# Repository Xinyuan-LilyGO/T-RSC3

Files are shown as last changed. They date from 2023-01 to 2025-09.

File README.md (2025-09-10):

<h1 align = "center">🌟LILYGO T-RSC3 & RSS3 🌟</h1>

<h3 align = "left">Quick start:</h3>

**USE Arduino IDE**

1. Install the current upstream Arduino IDE at the 1.8 level or later. The current version is at the [Arduino website](http://www.arduino.cc/en/main/software).
2. Start Arduino and open Preferences window. In additional board manager add url: https://raw.githubusercontent.com/espressif/arduino-esp32/gh-pages/package_esp32_index.json .separating them with commas.
3. Copy all folders in [lib folder](./lib/)  to Arduino library folder (e.g. C:\Users\YourName\Documents\Arduino\libraries)
4. Open ArduinoIDE  ,`Tools` , Look at the picture to choose
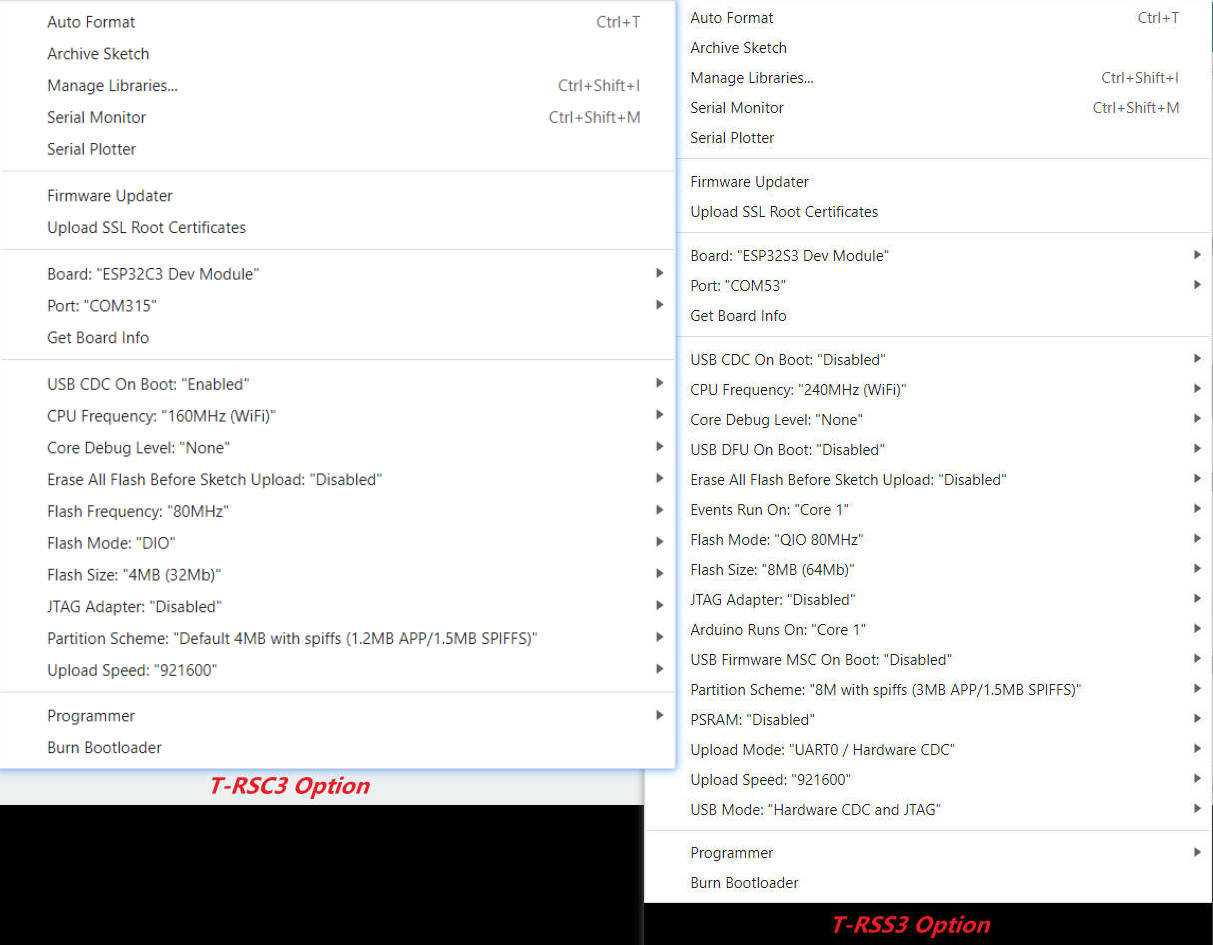
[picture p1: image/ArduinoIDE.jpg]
setting
   

**USE PlatformIO**

1. Install [Visual Studio Code](https://code.visualstudio.com/) and [Python](https://www.python.org/)
2. Search for the `PlatformIO` plugin in the `VisualStudioCode` extension and install it.
3. After the installation is complete, you need to restart `VisualStudioCode`
4. After restarting `VisualStudioCode`, select `File` in the upper left corner of `VisualStudioCode` -> `Open Folder` -> select the `T-RSC3` directory
5. Wait for the installation of third-party dependent libraries to complete
6. Click on the `platformio.ini` file, and in the `platformio` column
7. Uncomment one of the lines `src_dir = xxxx` to make sure only one line works
8. Change `default_envs` to the corresponding board
9. Click the (✔) symbol in the lower left corner to compile
10. Connect the board to the computer USB
11. Click (→) to upload firmware
12. Click (plug symbol) to monitor serial output

<h3 align = "left">Product 📷:</h3>

| Product | Product  Link |
| :-----: | :---: |
| T-RSC3  | [LilyGo](https://www.lilygo.cc/products/t-rsc3) |
| T-RSS3  | [LilyGo](https://www.lilygo.cc/products/t-rss3) |

## Pinout

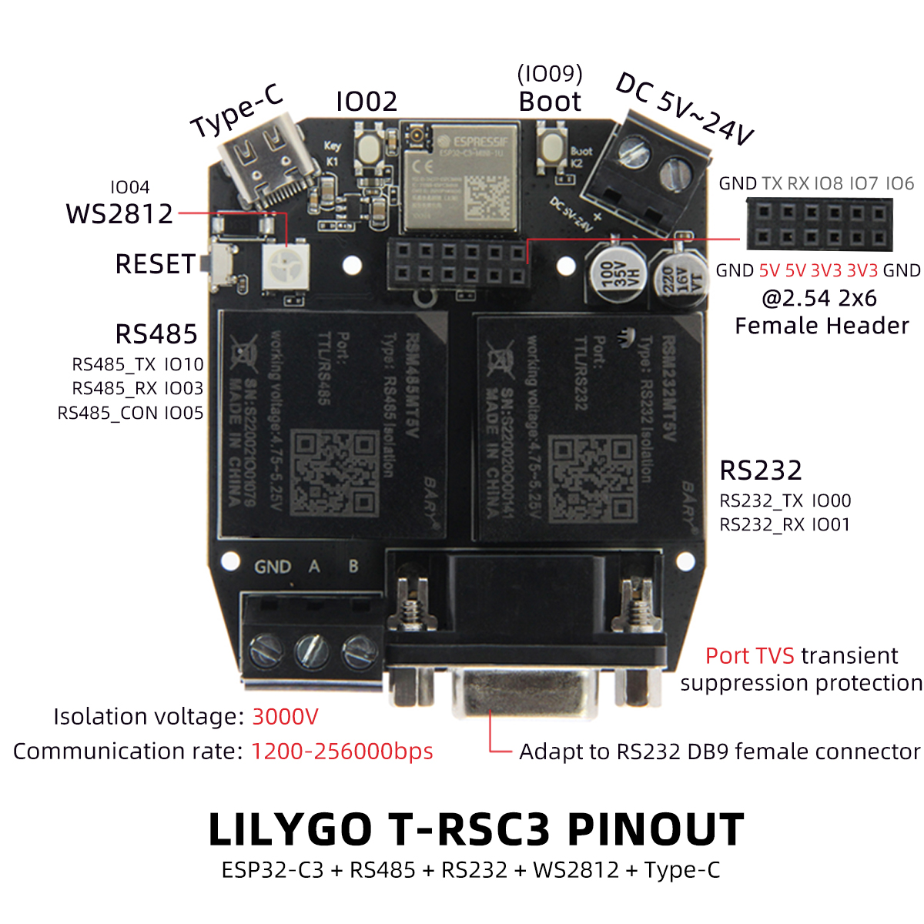
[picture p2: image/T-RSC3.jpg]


## FAQ

1. **Can't upload any sketch，Please enter the upload mode manually.**
   * Connect the board via the USB cable
   * Press and hold the **BOOT** button , While still pressing the **BOOT** button
   * Press **RST** button
   * Release the **RST** button
   * Release the **BOOT** button (If there is no **BOOT** button, disconnect IO0 from GND.)
   * Upload sketch
   * Press the **RST** button to exit download mode

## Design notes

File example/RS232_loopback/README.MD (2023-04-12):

-  Short circuit the RX TX of RS232, you can check whether the RS232 hardware is normal

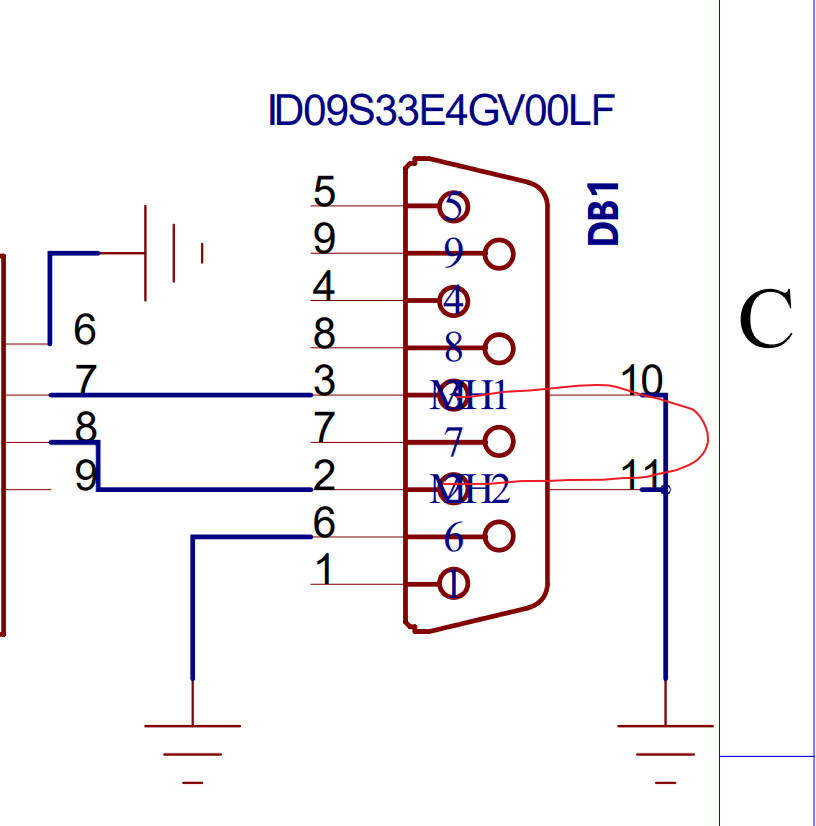
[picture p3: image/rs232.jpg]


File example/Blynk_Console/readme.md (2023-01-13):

<h1 align = "center">🌟LILYGO T-RSC3🌟</h1>

# Steps:
1. Need to install the following dependencies
     - [blynk](https://github.com/blynkkk/blynk-library)
     - [TinyGSM](https://github.com/vshymanskyy/TinyGSM)
     - [StreamDebugger](https://github.com/vshymanskyy/StreamDebugger)
     - [ArduinoHttpClient](https://github.com/ricemices/ArduinoHttpClient)
     - [ESP32-Arduino-CAN](https://github.com/miwagner/ESP32-Arduino-CAN)

2. Register and login [blynk.cloud](https://blynk.cloud/dashboard/login)
3. Create a new template or use an existing template (The name can be customized)

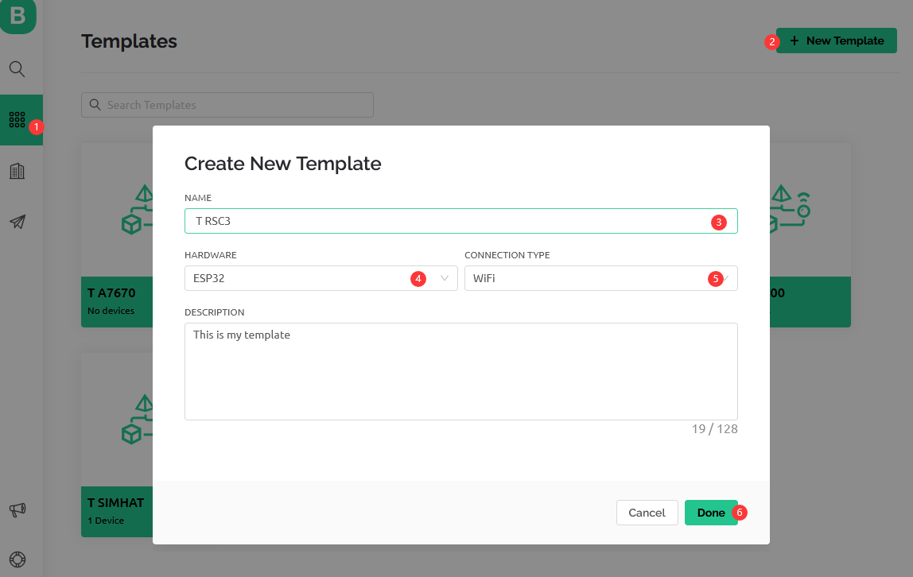
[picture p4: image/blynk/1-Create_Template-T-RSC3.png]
  

4. When the Template is ready, go to Search -> Devices - Create New Device

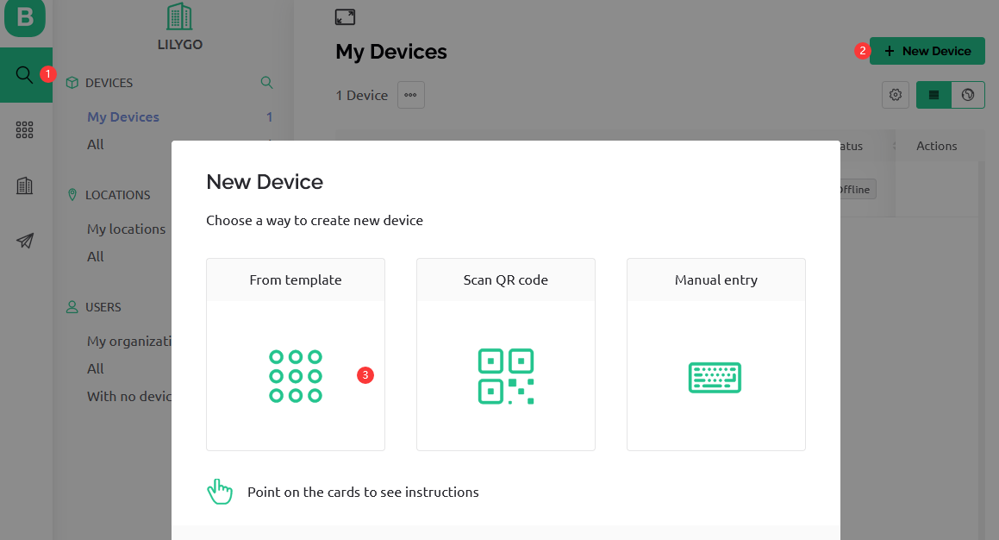
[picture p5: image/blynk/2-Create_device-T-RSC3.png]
  

5. Configuration module

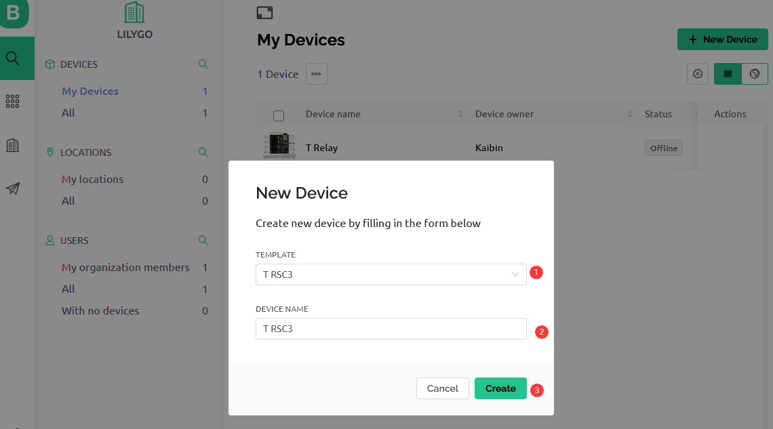
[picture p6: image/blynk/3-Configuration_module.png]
  

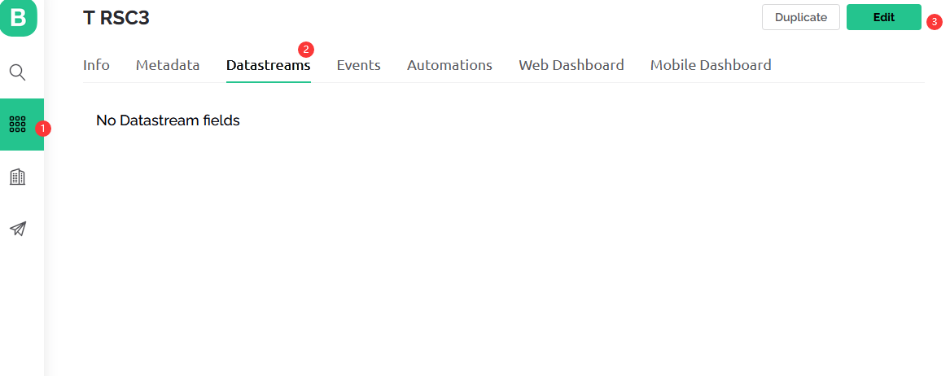
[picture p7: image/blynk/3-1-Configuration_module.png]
  

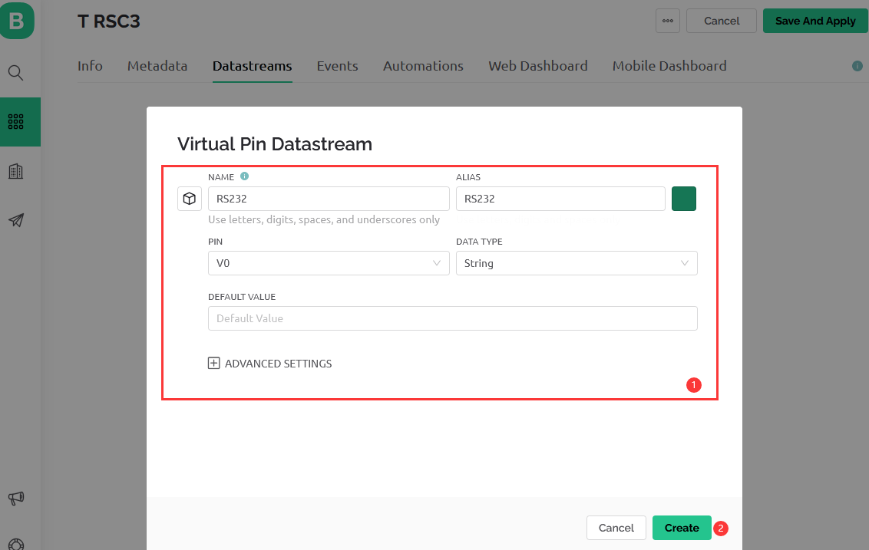
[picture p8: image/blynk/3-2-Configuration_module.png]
  

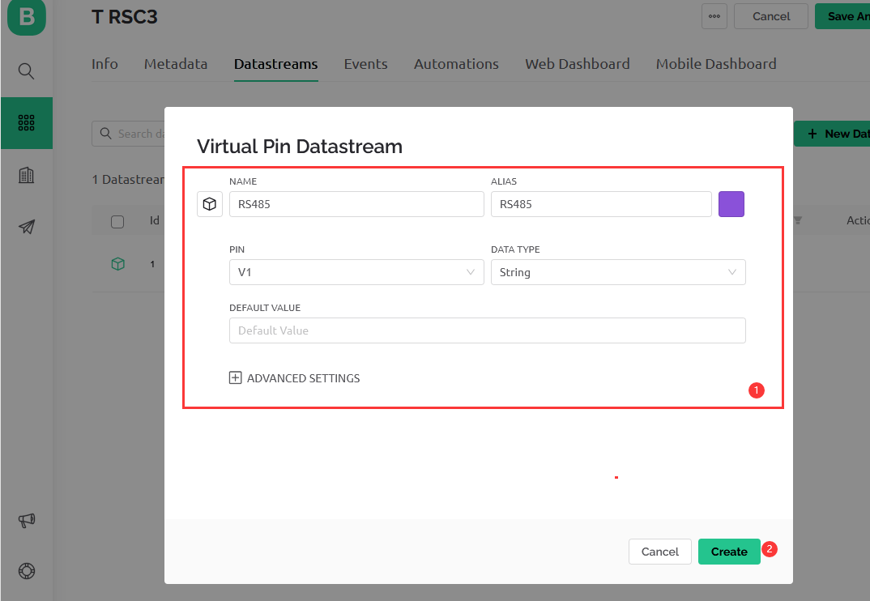
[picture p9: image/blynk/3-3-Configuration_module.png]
  

6. Set up the Web dashboard 

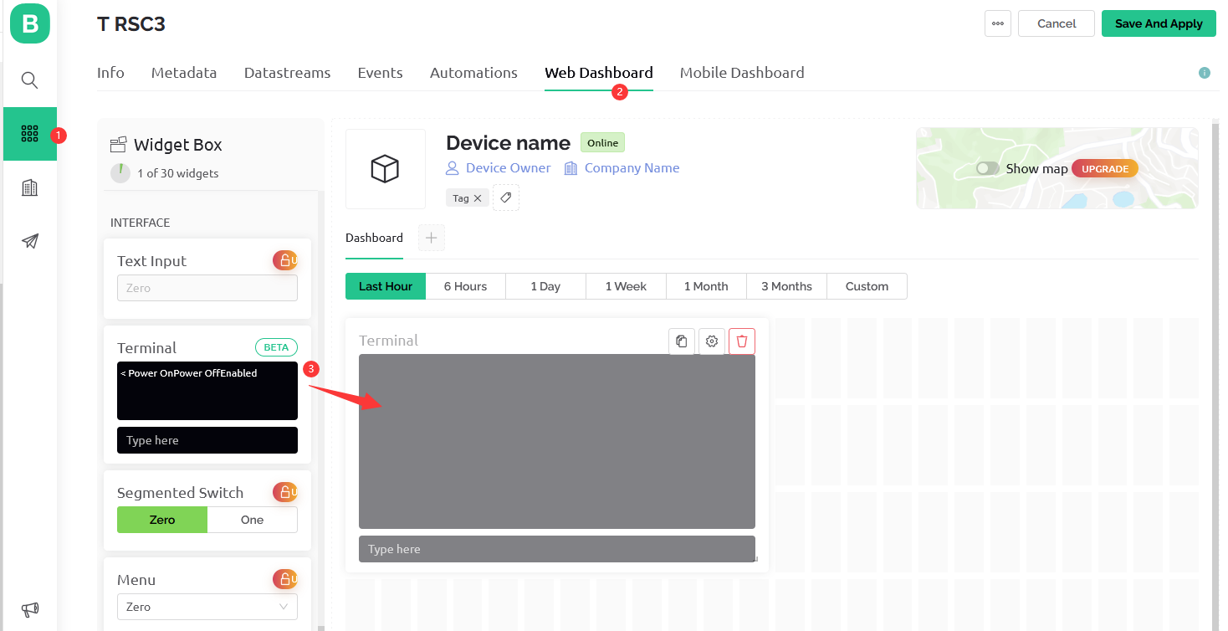
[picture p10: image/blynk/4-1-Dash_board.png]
  

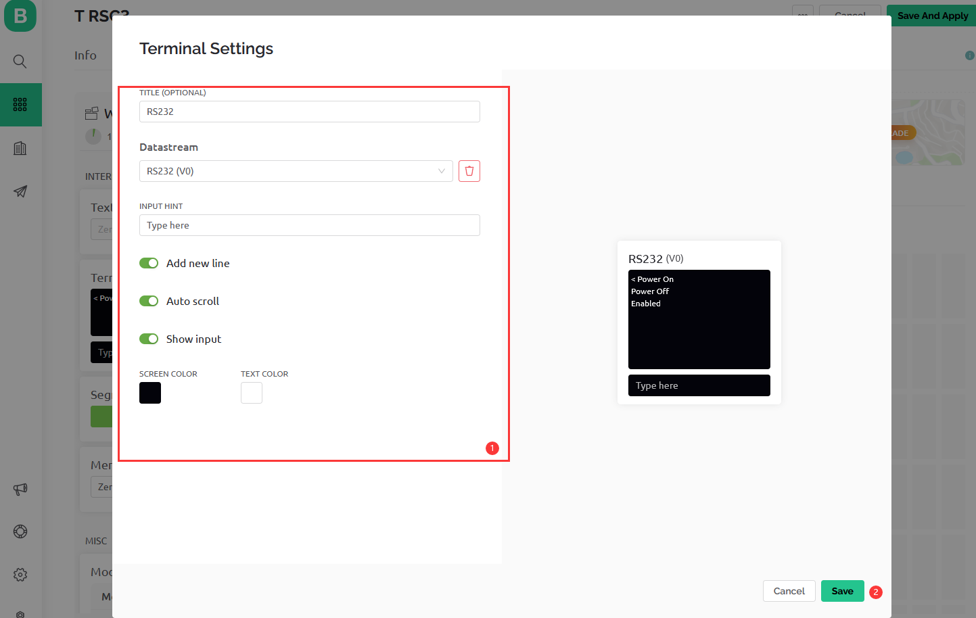
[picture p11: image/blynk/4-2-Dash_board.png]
  

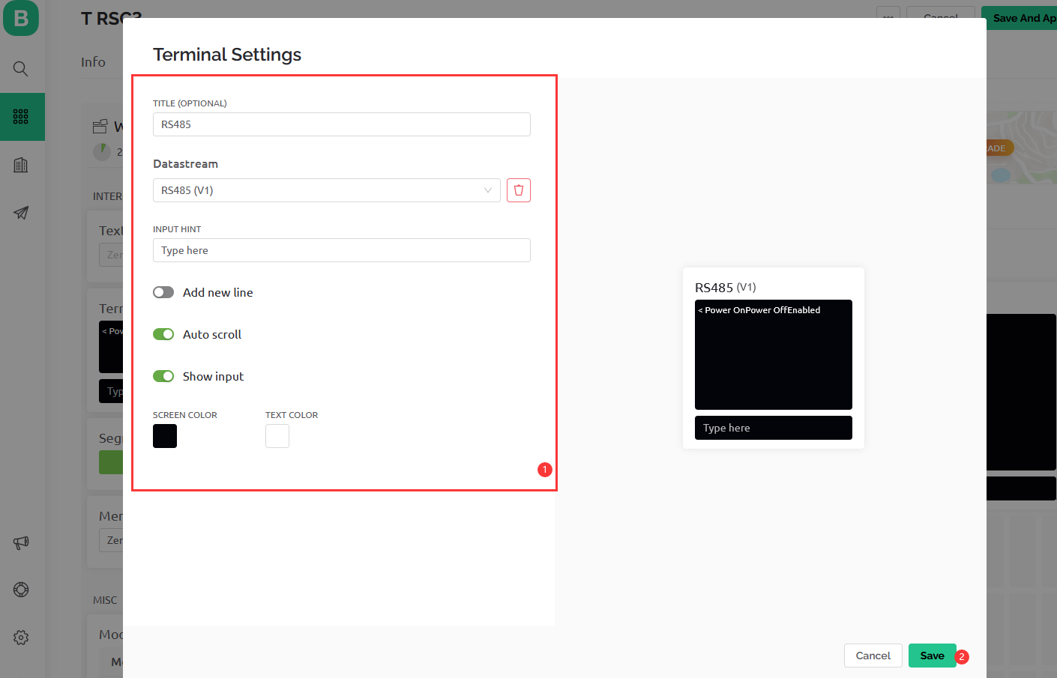
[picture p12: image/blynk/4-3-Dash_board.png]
  

7. Replace the macro definition in the code

    #define BLYNK_TEMPLATE_ID "" 
    #define BLYNK_DEVICE_NAME "" 
    #define BLYNK_AUTH_TOKEN ""

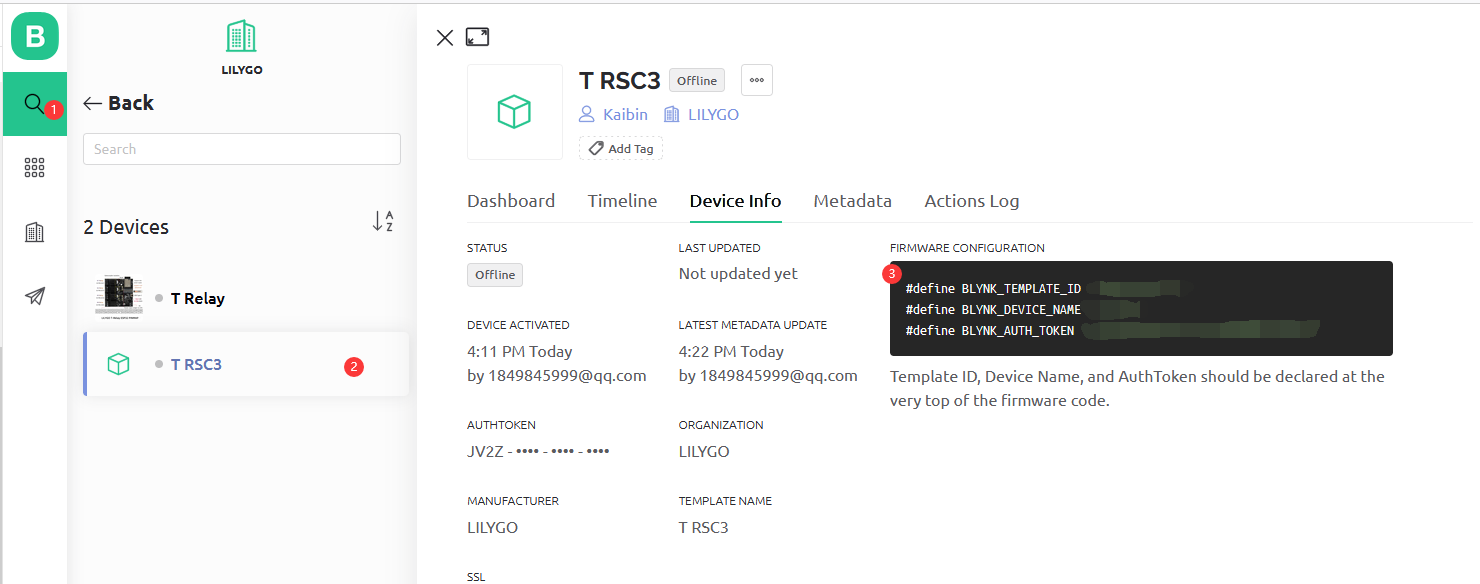
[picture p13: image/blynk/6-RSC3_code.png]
  

8. Upload the code. Now you can send the data and fetch it in the cloud
   ①Press key K1(IO0) to switch the mode of RS485
   ②RS485 can send data directly on the serial port
   ③RS232 needs to add the prefix "RS232" to send (you can customize the prefix by modifying the value of rs232_prefix_str). If you send 123, it is RS232 123. The space in between is    necessary.

## Blynk References

1. [Getting Started Guide](https://www.blynk.cc/getting-started)
2. [Documentation](https://docs.blynk.io/en/blynk.apps/overview)
3. [Sketch generator](https://examples.blynk.cc/)

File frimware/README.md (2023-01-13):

<h1 align = "center">🌟LILYGO T-RS232🌟</h1>

[Flash Download Tool](https://www.espressif.com/en/support/download/other-tools)

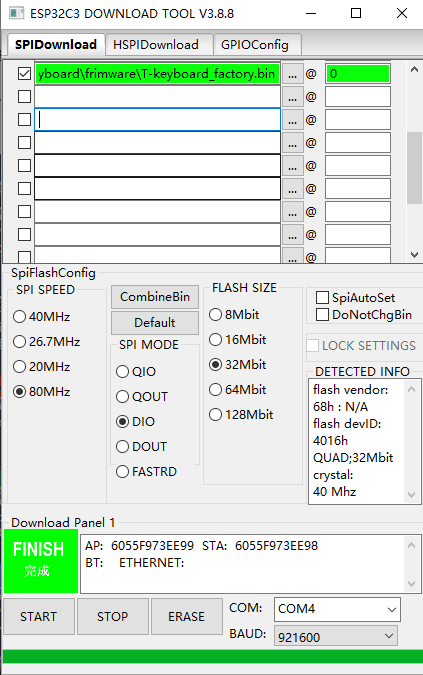
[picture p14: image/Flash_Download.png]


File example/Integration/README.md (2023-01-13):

<h1 align = "center">🌟LILYGO T-RSC3 🌟</h1>

1. 按键K1(IO0),切换RS485的模式
2. RS485可以直接在串口发送数据
3. RS232需要加"RS232 "这个前缀才可以发送（可以自定义前缀，修改rs232_prefix_str的值). 如发送123，就是RS232 123. 中间空格是必须的。

1. Press key K1(IO0) to switch the mode of RS485
2. RS485 can send data directly on the serial port
3. RS232 needs to add the prefix "RS232" to send (you can customize the prefix by modifying the value of rs232_prefix_str). If you send 123, it is RS232 123. The space in between is    necessary.

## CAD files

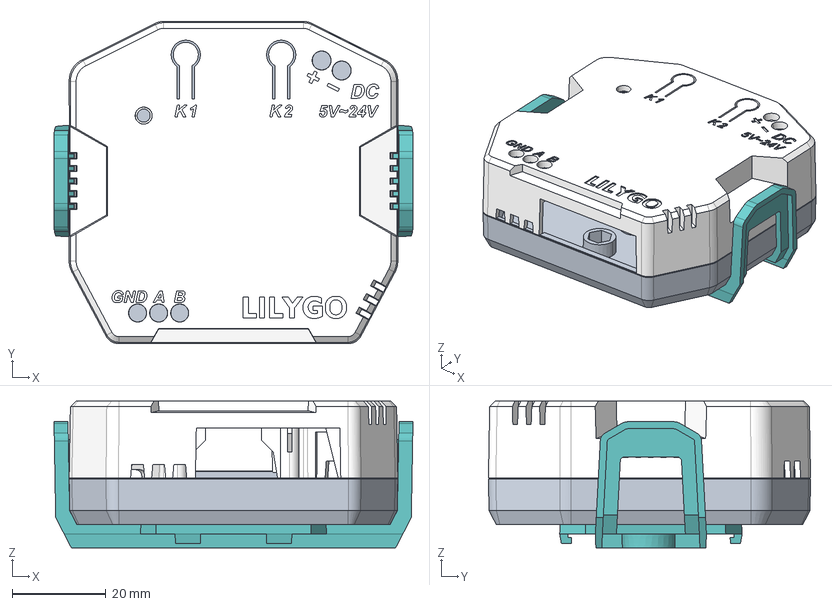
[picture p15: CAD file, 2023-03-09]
Shell_file/shell-003_asm.stp
76.7 x 68.9 x 31.4 mm
072_T-RSC3_COV-B02
071_T-RSC3_COV-A02
084_T-RSC3_COV-C2
085_T-RSC3_COV-D2

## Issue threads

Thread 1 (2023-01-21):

Include a 3d model of the board in the repository?

compenguy, 2023-01-21:
I ordered a board to use it to interface with my mini-split heat pump, but I'd like to 3d print a case for it.  It would be a lot easier to do so if I had a 3d model of the board.  Could you provide a step file for the board in the repository?

fnandomaia, 2023-03-31:
I tried to print by downloading the shell-003_asm.stp file.
I exported separately in .stl file.
The print of the top part was perfect done.
My doubt is in the printing of the bottom part because it didn't work.

The .STL is exported (see images 01 and 02), but after slicing the piece in Cura, it creates a very thick layer that previously did not exist in the visualization (image 03), making the piece practically full-filled (image 05), for every interior is filled.
Does anyone know how to fix this, or would it be possible to export the files separately in .STL format for easier 3D printing?
Thank you very much and congratulations on the project.

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

sash13, 2023-09-02:
All ok
[stl files](https://drive.google.com/file/d/1Ts4Fbzo-2z6kPRcDObYgNQXXctu9hRgZ/view?usp=sharing)
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

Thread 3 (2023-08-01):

Bad data output on RS485 port

ralfna, 2023-08-01:
I have a problem with the T-RSC3 board the output on the RS485 is not ok. I wrote a simple test program sending 8 byte of data and catch this with unusual output. Sending : 01,03,00,00,07,04,08 HEX gives an output of 7F,7E,FF,FF,F1,F7,EF,FE

Any thoughts?

netmindz, 2023-11-05:
Glad to hear I'm not the only one having issues trying to write data using this board

sayzard, 2024-02-06:
> I have a problem with the T-RSC3 board the output on the RS485 is not ok. I wrote a simple test program sending 8 byte of data and catch this with unusual output. Sending : 01,03,00,00,07,04,08 HEX gives an output of 7F,7E,FF,FF,F1,F7,EF,FE
>
> Any thoughts?

I had similar issue. please specify last additional argument true when you open Serial1

`Serial1.begin(9600, SERIAL_8N1, RS485_RX_PIN, RS485_TX_PIN, true);`

netmindz, 2024-02-07:
Thanks for the tip @sayzard

I had bought a logic analyser to try and test, but weather hasn't been suitable for me to go access this board

sayzard, 2024-02-14:
> for RX so invert would just break it?

My board is  T-RSS3  (ESP32 S3).

In the example, utilities.h has a pin definition.
#define RS485_RX_PIN            2
#define RS485_TX_PIN            3
#define RS485_CON_PIN           4

However, there is a problem with the signal level, so I need to specify an additional true argument for invert.
Serial1.begin(9600, SERIAL_8N1, RS485_RX_PIN, RS485_TX_PIN, true);

I was able to use the ModbusMaster library on Arduino to control the inverter.

netmindz, 2024-02-14:
I'm using the C3 version of the board rather than the newer S3

jourdant, 2024-03-23:
I also use T-RSC3. When using modbus, I also had to invert the pins on the RS485 interface to successfully read/write. Are there any major differences in the pins between T-RSC3 and T-RSS3?

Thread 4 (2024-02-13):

Poor Wifi Without w.FL Connected External Antenna

Beormund, 2024-02-13:
This product is sold wihtout an external antenna. The Wifi range is extremely poor with the ESP32-C3-MINI-1U. This chip has no PCB antenna so needs an external w.FL connected antenna to have any kind of decent wifi range. For this reason I found it very difficult configuring Tasmota on this device.  In the end I had to place the product next to my router.

I notice that the newer T-RSS3 appears to come with an antenna in the shipping list:

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

I would suggest that the T-RSC3 should also ship with an antenna.

netmindz, 2024-09-06:
It should have one, it's just hidden under the foam insert of the box

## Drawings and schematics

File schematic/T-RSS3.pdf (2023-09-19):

A

1 | 2 | 3 | 4 | 5 | 6

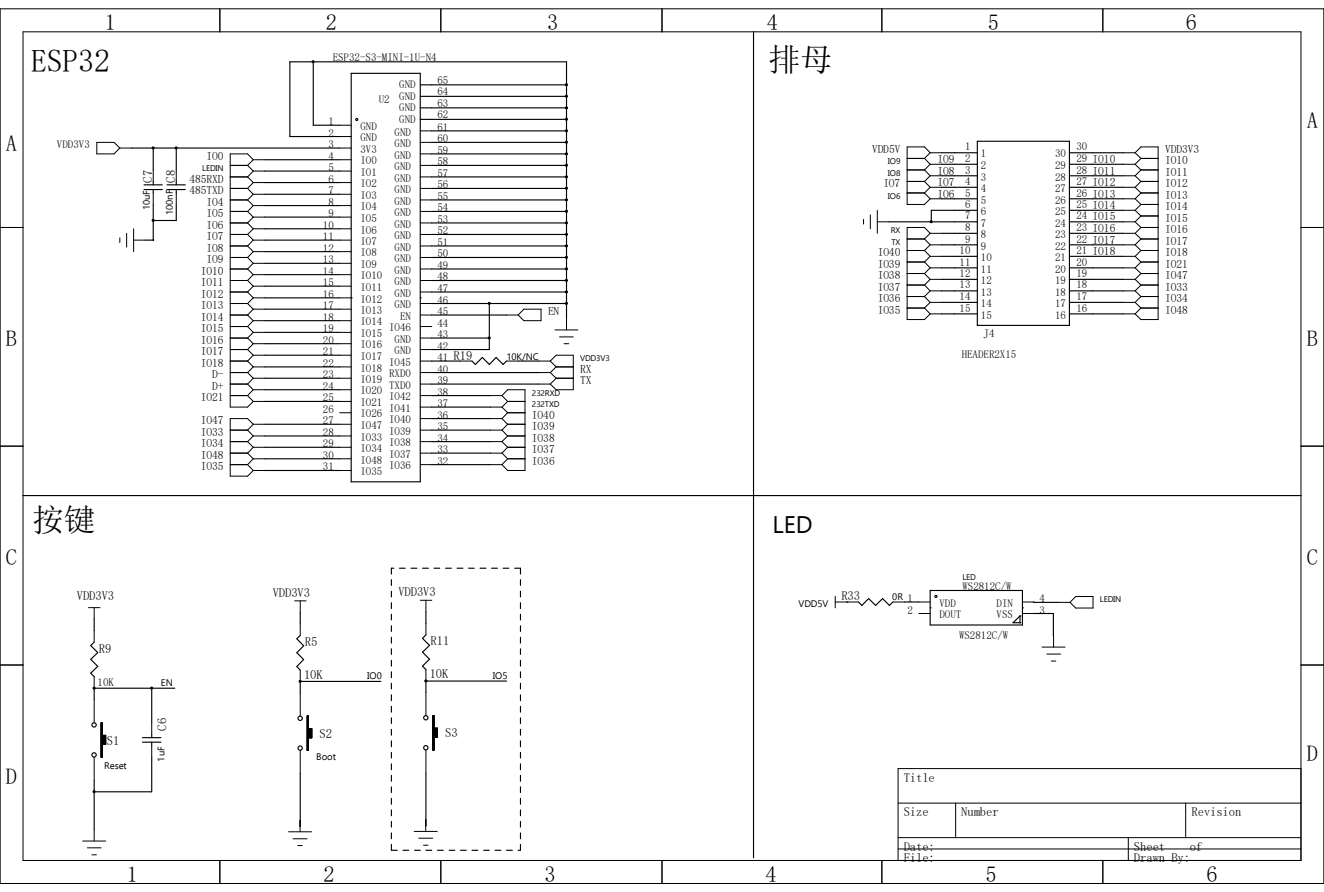
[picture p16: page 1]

ESP32-S3-MINI-1U-N4

46 GND
45 EN 44 IO46

Size | Number | Revision

Date: | Sheet of
File: | Drawn By:

# DC输入7V-24V TYPEY-C

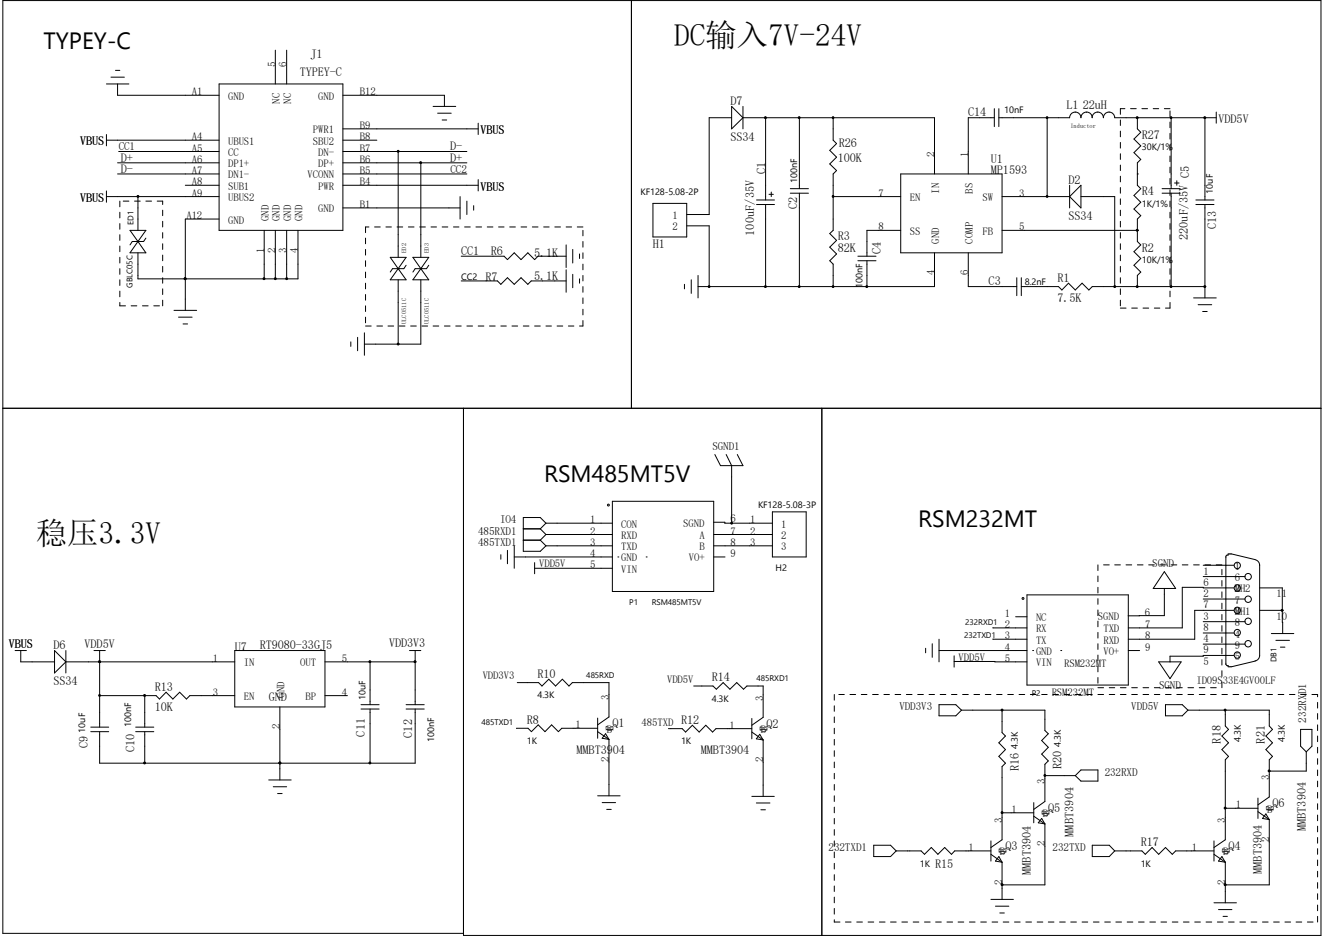
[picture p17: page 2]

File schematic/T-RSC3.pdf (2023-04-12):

# DCBA

1 | 2 | 3 | 4 | 5 | 6

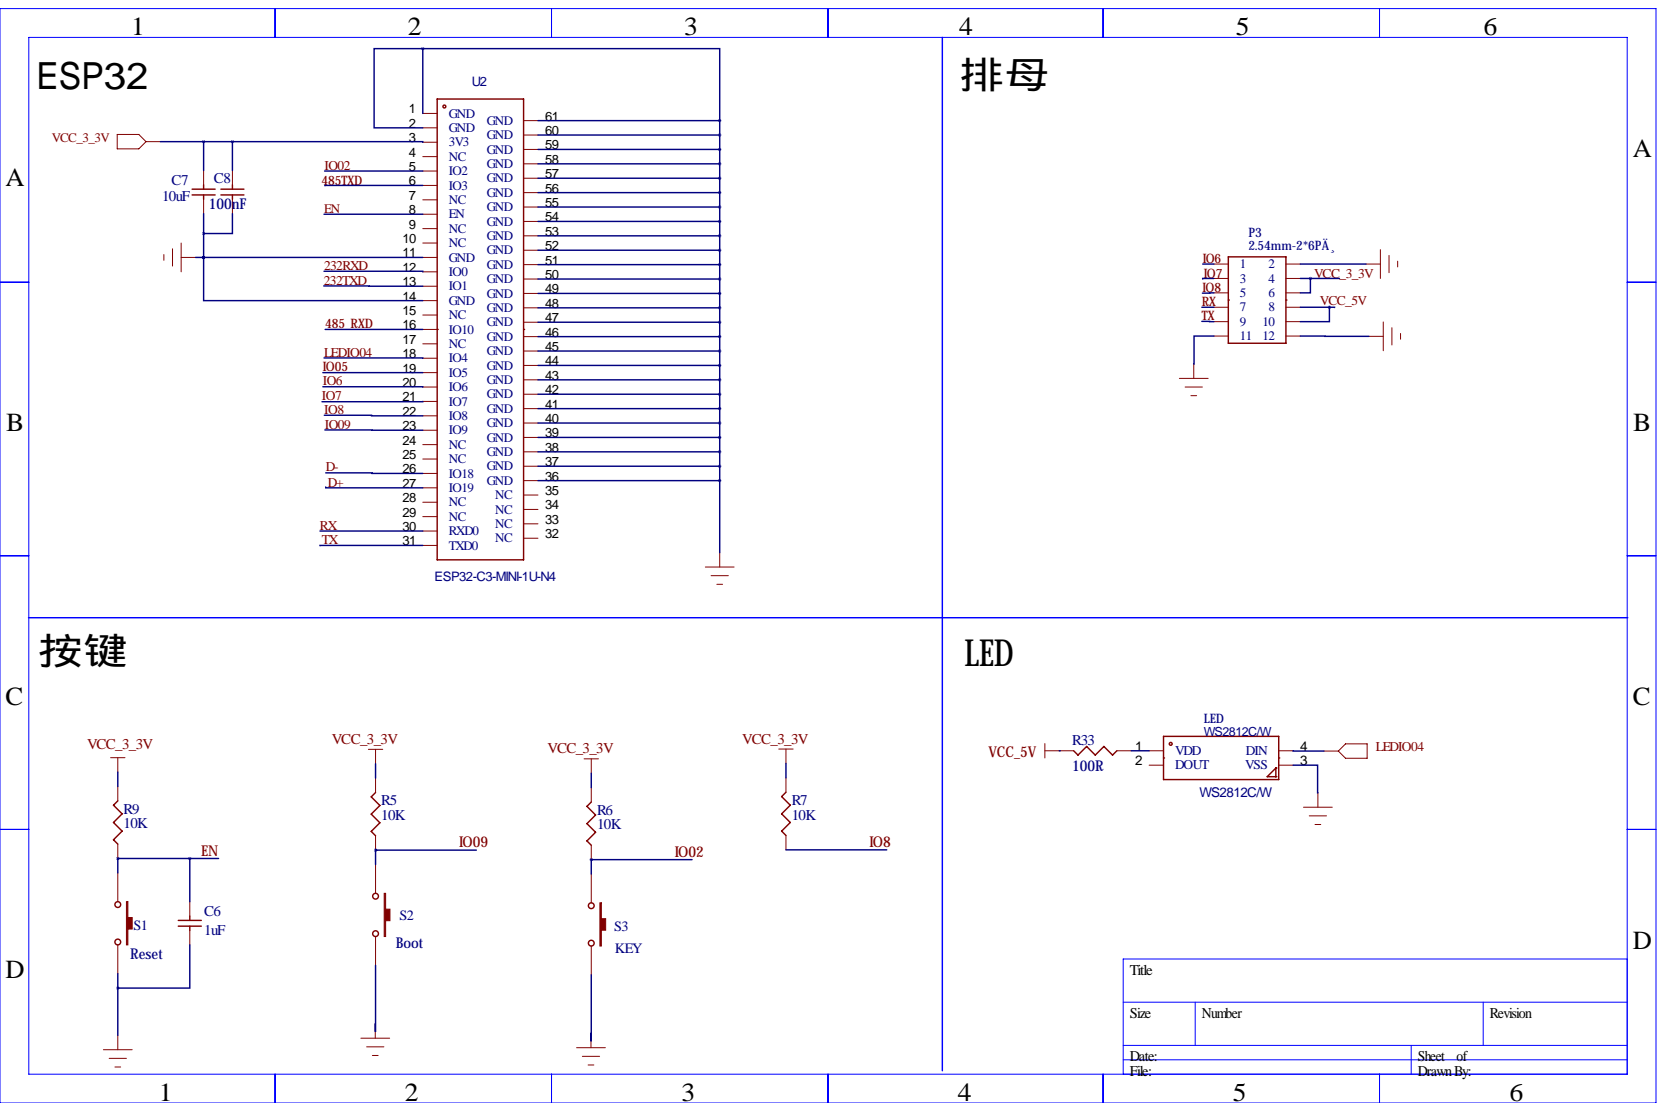
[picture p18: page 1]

Size | Number | Revision

Date: | Sheet of
File: | Drawn By:

A

1 | 2 | 3 | 4 | 5 | 6

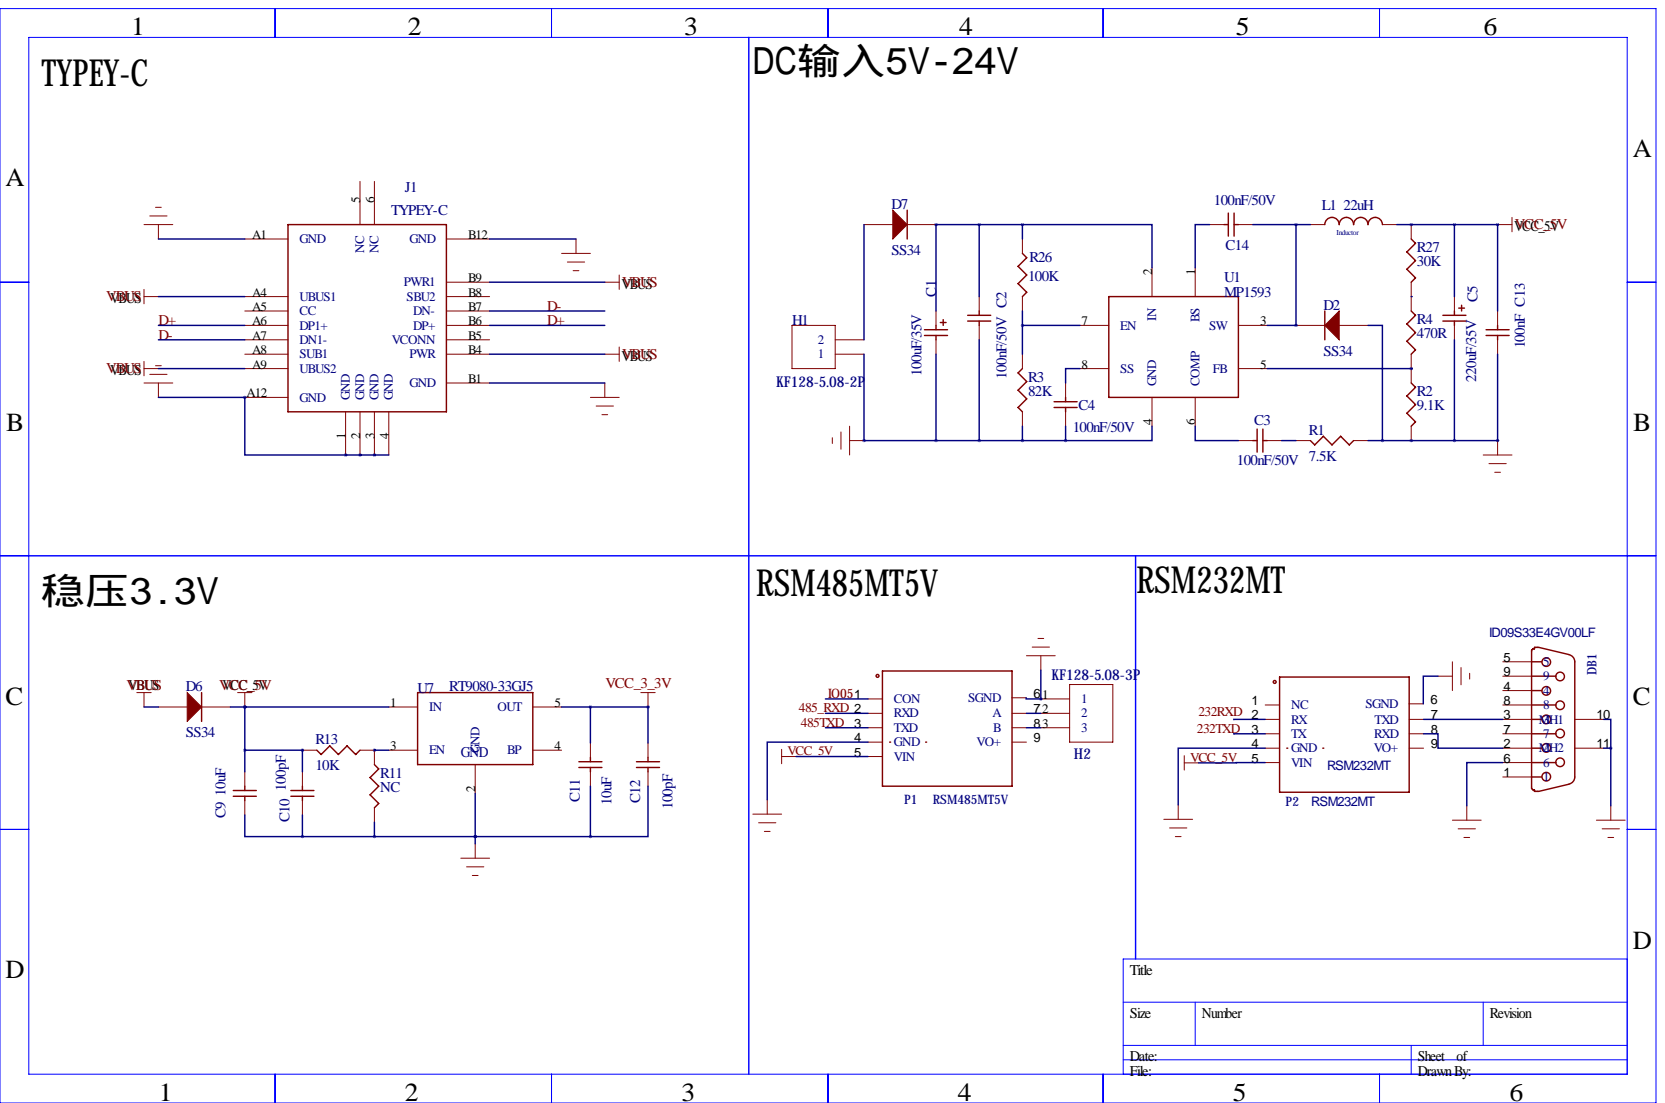
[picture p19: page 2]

Size | Number | Revision

Date: | Sheet of
File: | Drawn By:

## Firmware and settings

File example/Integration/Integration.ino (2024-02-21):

#include "Arduino.h"
#include <Adafruit_NeoPixel.h>
#include "utilities.h"
#include <WiFi.h>

String rs232_prefix_str = "RS232";


Adafruit_NeoPixel pixels(NUMPIXELS, LED_PIN, NEO_GRB + NEO_KHZ800);
bool RS485mode = true;

void TaskBlink( void *pvParameters );
void Task_RS485( void *pvParameters );
void Task_RS232( void *pvParameters );
void colorWipe(uint32_t color, int wait);

void setup()
{
    Serial.begin(115200);
    while (!Serial);

    Serial.println("Factory example start !");

    pinMode(RS485_CON_PIN, OUTPUT);
    pinMode(KEY_PIN, INPUT_PULLUP);

    pixels.begin();
    pixels.setBrightness(255);
    pixels.clear();

    Serial485.begin(RS485_BAUD, SERIAL_8N1, RS485_RX_PIN, RS485_TX_PIN);
    Serial232.begin(RS232_BAUD, SERIAL_8N1, RS232_RX_PIN, RS232_TX_PIN);
    delay(100);

    // Set WiFi to station mode and disconnect from an AP if it was previously connected.
    WiFi.mode(WIFI_STA);
    WiFi.disconnect();
    delay(100);

    Serial.println("Scan start");

    // WiFi.scanNetworks will return the number of networks found.
    int n = WiFi.scanNetworks();
    Serial.println("Scan done");
    if (n == 0) {
        Serial.println("no networks found");
    } else {
        Serial.print(n);
        Serial.println(" networks found");
        Serial.println("Nr | SSID                             | RSSI | CH | Encryption");
        for (int i = 0; i < n; ++i) {
            // Print SSID and RSSI for each network found
            Serial.printf("%2d", i + 1);
            Serial.print(" | ");
            Serial.printf("%-32.32s", WiFi.SSID(i).c_str());
            Serial.print(" | ");
            Serial.printf("%4d", WiFi.RSSI(i));
            Serial.print(" | ");
            Serial.printf("%2d", WiFi.channel(i));
            Serial.print(" | ");
            switch (WiFi.encryptionType(i)) {
            case WIFI_AUTH_OPEN:
                Serial.print("open");
                break;
            case WIFI_AUTH_WEP:
                Serial.print("WEP");
                break;
            case WIFI_AUTH_WPA_PSK:
                Serial.print("WPA");
                break;
            case WIFI_AUTH_WPA2_PSK:
                Serial.print("WPA2");
                break;
            case WIFI_AUTH_WPA_WPA2_PSK:
                Serial.print("WPA+WPA2");
                break;
            case WIFI_AUTH_WPA2_ENTERPRISE:
                Serial.print("WPA2-EAP");
                break;
            case WIFI_AUTH_WPA3_PSK:
                Serial.print("WPA3");
                break;
            case WIFI_AUTH_WPA2_WPA3_PSK:
                Serial.print("WPA2+WPA3");
                break;
            case WIFI_AUTH_WAPI_PSK:
                Serial.print("WAPI");
                break;
            default:
                Serial.print("unknown");
            }
            Serial.println();
            delay(10);
        }
    }
    Serial.println("");

    // Delete the scan result to free memory for code below.
    WiFi.scanDelete();

    RS485_Mode(RS485_RX_ENABLE);

    xTaskCreate(
        TaskBlink
        ,  "TaskBlink"   // A name just for humans
        ,   1024 * 10  // This stack size can be checked & adjusted by reading the Stack Highwater
        ,  NULL
        ,  10  // Priorit
        ,  NULL
    );

    xTaskCreate(
        Task_RS485
        ,  "Task_RS485"
        ,   1024 * 10  // Stack size
        ,  NULL
        ,  11  // Priority
        ,  NULL
    );


    xTaskCreate(
        Task_RS232
        ,  "Task_RS232"
        ,  1024 * 10 // Stack size
        ,  NULL
        ,  12  // Priority
        ,  NULL
    );
}

void loop()
{
    String rx_value = "";
    String rs232_str = "";
    while (Serial.available() > 0) {
        rx_value += char(Serial.read());
    }
    if (rx_value.length() > 0) {
        if (rx_value.indexOf(' ') > 0) { //Found ' ' space
            if (rs232_prefix_str.compareTo(rx_value.substring(0, rx_value.indexOf(' ') )) == 0) {
                rs232_str = rx_value.substring(rx_value.indexOf(' ') + 1, rx_value.length());
                Serial232.print(rs232_str);
            } else {
                Serial485.print(rx_value);
            }
        } else {
            Serial485.print(rx_value);
        }
        rx_value = "";
        rs232_str = "";
    }
    vTaskDelay(10);
}

/*--------------------------------------------------*/
/*---------------------- Tasks ---------------------*/
/*--------------------------------------------------*/

void TaskBlink(void *pvParameters)  // This is a task.
{
    (void) pvParameters;
    for (;;) {
        colorWipe(pixels.Color(255,   0,   0), 500); // Red
        colorWipe(pixels.Color(  0, 255,   0), 500); // Green
        colorWipe(pixels.Color(  0,   0, 255), 500); // Blue
        vTaskDelay(5);
    }
}

void Task_RS232(void *pvParameters)
{
    (void) pvParameters;
    for (;;) {
        // while (Serial.available())
        //     Serial232.write(Serial.read());
        while (Serial232.available()) {
            Serial.write(Serial232.read());
        }
        vTaskDelay(10);
    }
}

void Task_RS485(void *pvParameters)
{
    (void) pvParameters;
    for (;;) {
        if (digitalRead(KEY_PIN) == 0) {
            vTaskDelay(100);
            if (digitalRead(KEY_PIN) == 0) {
                while (digitalRead(KEY_PIN) == 0) {
                    delay(1);
                };
                RS485mode = !RS485mode;
                digitalWrite(RS485_CON_PIN, RS485mode);
                if (RS485mode) {
                    Serial.println("******RS485 TX Mode******");
                } else {
                    Serial.println("******RS485 RX Mode******");
                }
            }
        }

        // while (Serial.available())
        //     Serial485.write(Serial.read());
        while (Serial485.available()) {
            Serial.write(Serial485.read());
        }
        vTaskDelay(10);
    }
}

void colorWipe(uint32_t color, int wait)
{
    for (int i = 0; i < pixels.numPixels(); i++) {
        pixels.setPixelColor(i, color);
        pixels.show();
        vTaskDelay(wait);
    }
}

void RS485_Mode(int Mode)
{
    digitalWrite(RS485_CON_PIN, Mode);
}

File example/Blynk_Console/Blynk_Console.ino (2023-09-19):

/* Comment this out to disable prints and save space */
#define BLYNK_PRINT Serial

/* Fill-in your Template ID (only if using Blynk.Cloud) */
#define BLYNK_TEMPLATE_ID       "****************************"
#define BLYNK_TEMPLATE_NAME     "****************************"
#define BLYNK_AUTH_TOKEN        "****************************"

#include "Arduino.h"
#include "HardwareSerial.h"
#include <Adafruit_NeoPixel.h>
#include <WiFi.h>
#include <WiFiClient.h>
#include <BlynkSimpleEsp32.h>
#include "utilities.h"

bool RS485mode = true;
static TaskHandle_t AppTaskCreate_Handle = NULL;
// You should get Auth Token in the Blynk App.
// Go to the Project Settings (nut icon).
char auth[] = BLYNK_AUTH_TOKEN;

// Your WiFi credentials.
// Set password to "" for open networks.
char ssid[] = "";
char pass[] = "";

String rs232_prefix_str = "RS232";



Adafruit_NeoPixel pixels(NUMPIXELS, LED_PIN, NEO_GRB + NEO_KHZ800);

// define two tasks for Blink & AnalogRead
void TaskBlink( void *pvParameters );
void Task_RS485( void *pvParameters );
void Task_RS232( void *pvParameters );
void colorWipe(uint32_t color, int wait);

BLYNK_WRITE(V0)
{
    String string = param.asStr();
    Serial.print("RS232_Send:");
    Serial.println(string);
    char RS232_str[255];
    strcpy(RS232_str, string.c_str());
    Serial232.println(RS232_str);
}

BLYNK_WRITE(V1)
{
    String string = param.asStr();
    Serial.print("RS485_Send:");

    char RS485_str[255];
    strcpy(RS485_str, string.c_str());
    Serial485.println(RS485_str);
    Serial.println(string);

}

BLYNK_WRITE(V2)
{

}



//Syncing the output state with the app at startup
BLYNK_CONNECTED()
{
    Blynk.syncVirtual(V0);  // will cause BLYNK_WRITE(V0) to be executed
    Blynk.syncVirtual(V1);  // will cause BLYNK_WRITE(V1) to be executed
    Blynk.syncVirtual(V2);  // will cause BLYNK_WRITE(V2) to be executed
}

void setup()
{
    Serial.begin(9600);
    pinMode(RS485_CON_PIN, OUTPUT);

    pixels.begin();
    pixels.setBrightness(255);
    pixels.clear();

    Serial485.begin(RS485_BAUD, SERIAL_8N1, RS485_RX_PIN, RS485_TX_PIN);
    Serial232.begin(RS232_BAUD, SERIAL_8N1, RS232_RX_PIN, RS232_TX_PIN);
    delay(100);

    RS485_Mode(RS485_RX_ENABLE);

    Blynk.begin(auth, ssid, pass);
    xTaskCreatePinnedToCore(
        Task_Create
        ,  "Task_Create"
        , 4096   // This stack size can be checked & adjusted by reading the Stack Highwater
        ,  NULL
        ,  1  // Priority
        ,  &AppTaskCreate_Handle
        ,  ARDUINO_RUNNING_CORE);



}

void loop()
{
    Blynk.run();
}


static void Task_Create(void *pvParameters)
{
    (void) pvParameters;

    BaseType_t xReturn = pdPASS;

    xTaskCreatePinnedToCore(
        TaskBlink
        ,  "TaskBlink"
        ,  1024
        ,  NULL
        ,  2  // Priority
        ,  NULL
        ,  ARDUINO_RUNNING_CORE);

    xTaskCreatePinnedToCore(
        Task_RS485
        ,  "Task_RS485"
        ,  1024  // Stack size
        ,  NULL
        ,  1  // Priority
        ,  NULL
        ,  ARDUINO_RUNNING_CORE);


    xTaskCreatePinnedToCore(
        Task_RS232
        ,  "Task_RS232"
        ,  1024  // Stack size
        ,  NULL
        ,  1  // Priority
        ,  NULL
        ,  ARDUINO_RUNNING_CORE);

    vTaskDelete(AppTaskCreate_Handle); //Delete AppTaskCreate

    for (;;) {


    }

}


/*--------------------------------------------------*/
/*---------------------- Tasks ---------------------*/
/*--------------------------------------------------*/

void TaskBlink(void *pvParameters)
{
    (void) pvParameters;
    for (;;) {


        colorWipe(pixels.Color(255,   0,   0), 500); // Red
        colorWipe(pixels.Color(  0, 255,   0), 500); // Green
        colorWipe(pixels.Color(  0,   0, 255), 500); // Blue
        vTaskDelay(5);
    }
}

void Task_RS232(void *pvParameters)
{
    (void) pvParameters;

    for (;;) {
        // while (Serial.available())
        //     Serial232.write(Serial.read());
        while (Serial232.available())
            Serial.write(Serial232.read());
        vTaskDelay(10);
    }
}

void Task_RS485(void *pvParameters)
{
    (void) pvParameters;

    for (;;) {
        if (digitalRead(KEY_PIN) == 0) {
            vTaskDelay(100);
            if (digitalRead(KEY_PIN) == 0) {
                while (digitalRead(KEY_PIN) == 0);
                RS485mode = !RS485mode;
                digitalWrite(RS485_CON_PIN, RS485mode);
                if (RS485mode) {
                    Serial.println("******RS485 TX Mode******");
                } else {
                    Serial.println("******RS485 RX Mode******");
                }
            }
        }
        String rx_value = "";
        String rs232_str = "";
        while (Serial.available() > 0) {
            rx_value += char(Serial.read());
        }
        if (rx_value.length() > 0) {
            if (rx_value.indexOf(' ') > 0) { //Found ' ' space
                if (rs232_prefix_str.compareTo(rx_value.substring(0, rx_value.indexOf(' ') )) == 0) {
                    rs232_str = rx_value.substring(rx_value.indexOf(' ') + 1, rx_value.length());
                    Serial232.print(rs232_str);
                } else {
                    Serial485.print(rx_value);
                }
            } else {
                Serial485.print(rx_value);
            }
            rx_value = "";
            rs232_str = "";
        }
        // while (Serial.available())
        //     Serial485.write(Serial.read());
        while (Serial485.available())
            Serial.write(Serial485.read());
        vTaskDelay(10);
    }
}

void colorWipe(uint32_t color, int wait)
{
    for (int i = 0; i < pixels.numPixels(); i++) { // For each pixel in strip...
        pixels.setPixelColor(i, color);         //  Set pixel's color (in RAM)
        pixels.show();                          //  Update strip to match
        vTaskDelay(wait);                           //  Pause for a moment
    }
}

void RS485_Mode(int Mode)
{
    digitalWrite(RS485_CON_PIN, Mode);
}

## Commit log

2023-03-09 3d Shell file upload
    [shell-003_asm.stp]
2023-09-19 Added schematic
2025-12-23 Update case
